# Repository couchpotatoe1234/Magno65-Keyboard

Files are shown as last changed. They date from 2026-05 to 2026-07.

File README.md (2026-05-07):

## Magno65
The Magno65 is a 65% keyboard that I designed because I wanted to try working with magnets on a functional design. I spent many hours working on PCB, Case, and firmware. This is currently still a work in progress.
Screenshot 2026-04-27 at 5 32 24 PM
(I don't have 3d models of the switches or keycaps :( )
Screenshot 2026-04-27 at 5 33 36 PM
It will use N52 Neodymium magnets that are 5mmx2mm in the PCB and on the bottom of the case, allowing the plate and the PCB to levitate. It will use a Raspberry Pi Pico RP2040 as the MCU and will use 1N4148 diodes.
Screenshot 2026-04-17 at 4 45 55 PM
The case itself is two parts, so it is 3D-printable. I currently have some untested firmware that will be tested when I make this project. Heres the aproximate BOM currently.
| Name | Purpose | Quantity | Total Cost (USD) | Link | Distributor |
|---|---|---|---|---|---|
| PCB | THE PCB, THE MAIN PART | 1 | 22.60 | https://jlcpcb.com | JLCPCB |
| N52 Neodymium magnets | to levitate the PCB (smallest pack I could find) | 1 | 12.04 | https://www.greenstuffworld.com/en/neodymium-magnets-n52/503-neodymium-magnets-5x2mm-50-units-n52.html | Green Stuff World |
| Keyboard Stabilizers | to stabilize the keycaps | 1 | 7.55 | https://www.temu.com/gold-plated-plate-mounted-stabilizer-for-custom-mechanical-keyboard-2u-6-25u-g-601100064817086.html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 | Temu |
| usb micro to usb-c cable | to connect the keyboard to the computer | 1 | 2.71 | https://www.temu.com/5a-type-c-to-micro-usb-fast-charging-cable-data-tansmission-stable-current-micro-usb-to-type-c-fast-charging-data-cable-for-samsung-xiaomi-huawe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 | Temu |
| Keycaps | to cap the keys | 1 | 6.93 | https://www.temu.com/chic-keycaps-with-contour-lines-featuring--cherry-profile-consisting-of-97-keys--double-shot--for---keycaps-have-see-through--and-lines-g-601100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 | Temu |
| Pi Pico | the brains of the operation | 1 | 3.11 | https://www.temu.com/1pc-sensor-module-pico-development-board--pico---supports--python-low-power-consumption--compatible-with--ide-and-csdk-industrial-electronics-no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 | Temu |
| Male pin headers | these are to connect the pi to the board | 1 | 2.27 | https://www.temu.com/dual-row-2-54mm-pitch-male-pin--40-pin-pcb-connector-strip-for--embedded-systems-g-606045468466813.html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 | Temu |
| 1N4148 | the diodes to make the keyboard work | 1 | 2.32 | https://www.temu.com/100pcs-1n4148-in4148-do-35-switch-diode-uncharged-other-material-for--g-601100062954719.html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 | Temu |
| Key switches | these are the whole point of a mechanical keyboard | 1 | 19.99 | https://www.wobkey.com/collections/all/products/keebmonkey-wobkey-rainy75-pre-lubed-hmx-jwk-switches | WOBKEY |

Onshape Doc:https://cad.onshape.com/documents/eb77577446a4daf0ae7d46e7/w/089a16ad9c5a3741a09f3581/e/c99e91a4ffdbfdf9530019f2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
Screenshot 2026-04-27 at 5 40 28 PM

Here are some calculations proving that this is actually possible:

I have estimated that the total mass of the key switches(125g), keycaps(100g), diodes(20g), PCB(150g), MCU(5g), and Plate(30g) will reach around 430 grams. With 6 pairs of magnets, and the weight of the PCB section spread out across all the magnets, each magnet will need only to lift around 70 grams. The magnets have 575 grams of pull/push force when directly together. Using the inverse square law, I calculated, that at around 4mm of distance, the repelling force of the magnets will be aproximately 70 grams. therefore, the entire PCB assembly will float a comfortable 4 mm off of the bottom of the case. Including a keypress of around 50 grams for the switches, it will float a little over 3 mm off of the bottom of the case. Calculations were asissted by K&J Magnet calculator:https://www.kjmagnetics.com/magnet-strength-calculator.asp Therefore, one can conclude that this keyboard is entirely possible being levitated only by 6 pairs of magnets.

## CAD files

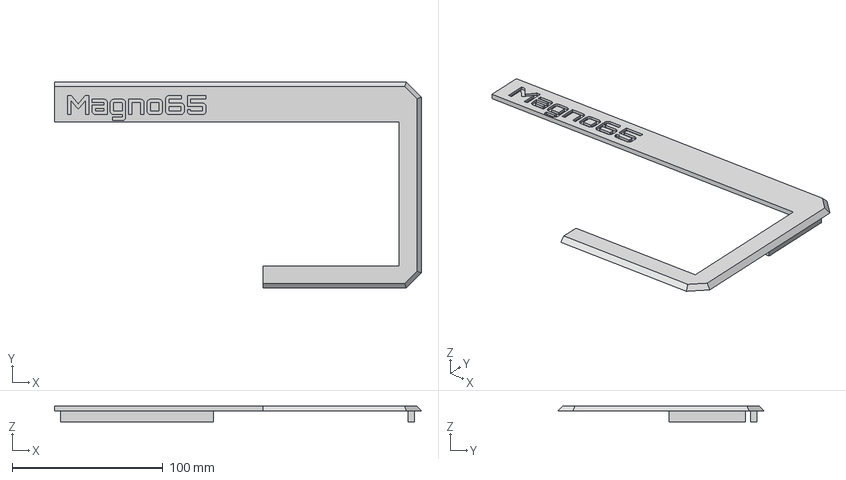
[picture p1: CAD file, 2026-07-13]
CAD/Magno65 parts - Top2.step
243.4 x 136.7 x 10.3 mm

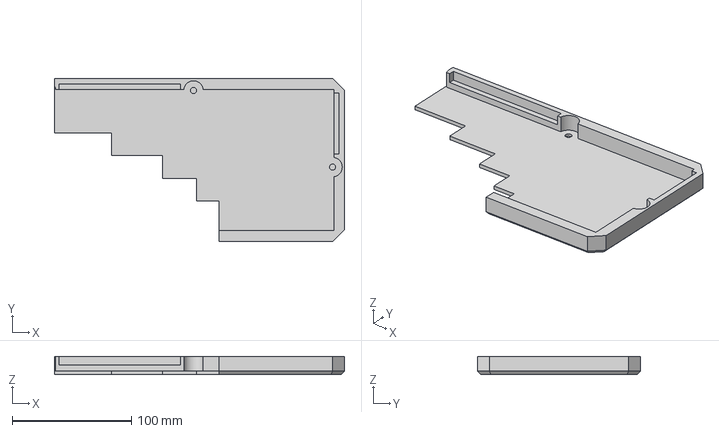
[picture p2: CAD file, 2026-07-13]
Production/Magno65 parts - Bottom1.step
243.4 x 136.7 x 15.5 mm

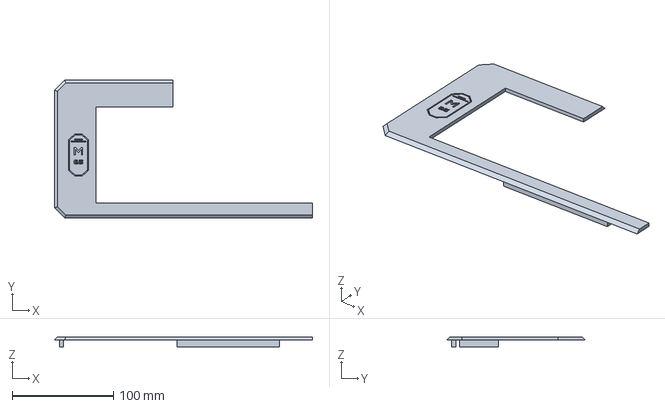
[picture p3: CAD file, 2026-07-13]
Production/Magno65 parts - Top1.step
255.3 x 136.7 x 10.3 mm

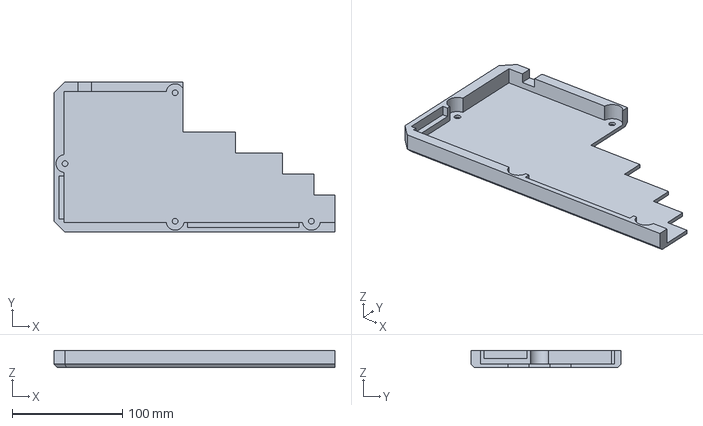
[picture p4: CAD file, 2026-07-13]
CAD/Magno65 parts - Bottom2.step
255.3 x 136.7 x 15.5 mm

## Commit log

2026-05-07 magnet proofs in README
2026-07-13 new case
    [Magno65 parts - Bottom1.step, Magno65 parts - Bottom2.step, Magno65 parts - Top1.step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]
